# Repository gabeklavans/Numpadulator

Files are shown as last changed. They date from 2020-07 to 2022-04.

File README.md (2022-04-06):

# Numpadulator
 QMK powered numpad + calculator
 
 ## TODO:
 * Write (or borrow) C calculator code
 * Incorporate calculator into Numpadulator
 * ~~Build working prototype~~

RGB Demo
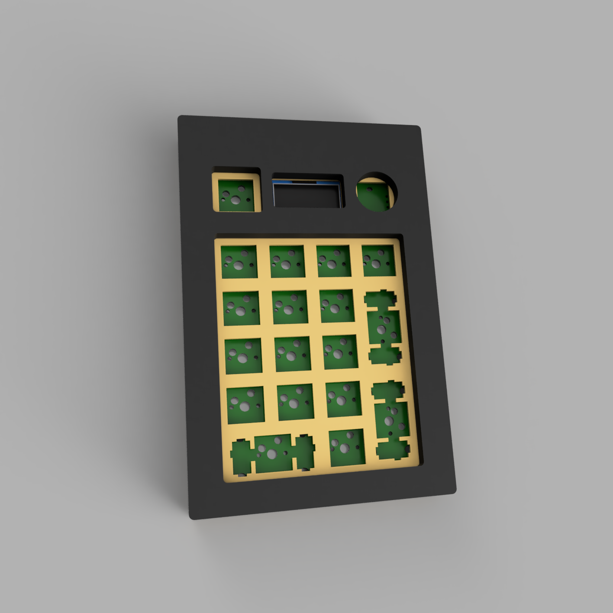
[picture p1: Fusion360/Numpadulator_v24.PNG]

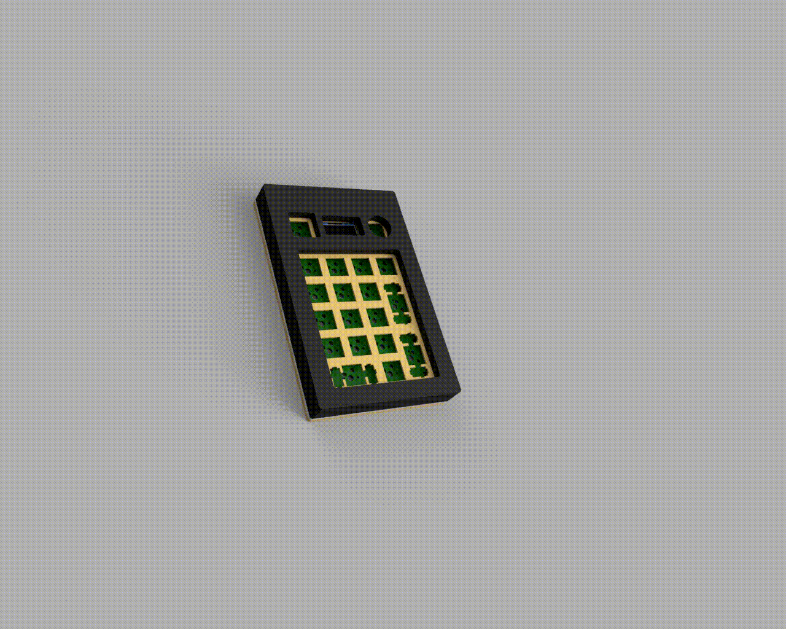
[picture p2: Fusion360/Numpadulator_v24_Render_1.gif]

PCB design

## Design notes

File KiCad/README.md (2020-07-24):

# Numpadulator
 QMK powered numpad + calculator

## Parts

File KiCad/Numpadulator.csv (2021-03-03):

Id | Designator | Package | Quantity | Designation | Supplier and ref
1 | C24,C23,C22,C21,C20,C19,C18,C17,C16,C15,C14,C13,C12,C11,C10,C9,C8,C7,C6,C5,C4,C3,C2,C1 | C_0805_2012Metric | 24 | 0.1uF
2 | D28,D27,D26,D25,D24,D23 | LED_SK6812MINI_PLCC4_3.5x3.5mm_P1.75mm | 6 | SK6812MINI
3 | R1 | R_0805_2012Metric | 1 | 470
4 | MX2,MX3,MX1 | MXOnly-2U-Hotswap | 3 | MX-NoLED
5 | SW16,SW2,SW1,SW12,SW15,SW14,SW13,SW11,SW10,SW9,SW8,SW7,SW5,SW4,SW3 | Cherry-MX_PCB-Mounted_SK6812-MINI-E_Kailh_Socket | 15 | Cherry_MX_RGB_WS2812
6 | SW19 | XDCR_PEC11R-4215F-S0024 | 1 | Rotary_Encoder_Switch
7 | D22,D21,D20 | SK6812-MINI-E | 3 | WS2816
8 | U2 | Adafruit_SSD1306 | 1 | OLED_SSD1306
9 | U1 | PRO_MICRO_C | 1 | PRO_MICRO_C
10 | D19,D18,D17,D16,D15,D14,D13,D12,D11,D10,D9,D8,D7,D6,D5,D4,D3,D2,D1 | D_SOD-123 | 19 | D_Small

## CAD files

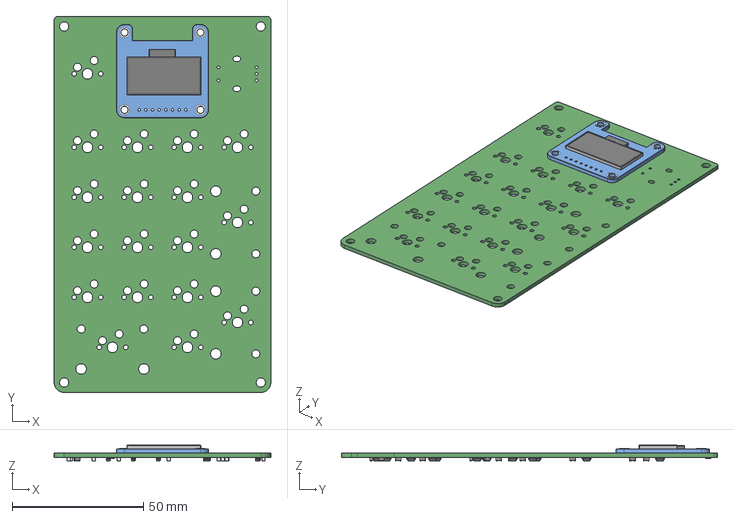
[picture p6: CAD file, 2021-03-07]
KiCad/Numpadulator.step
82.5 x 143.3 x 5.95 mm

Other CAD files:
Fusion360/Numpadulator v25.f3z

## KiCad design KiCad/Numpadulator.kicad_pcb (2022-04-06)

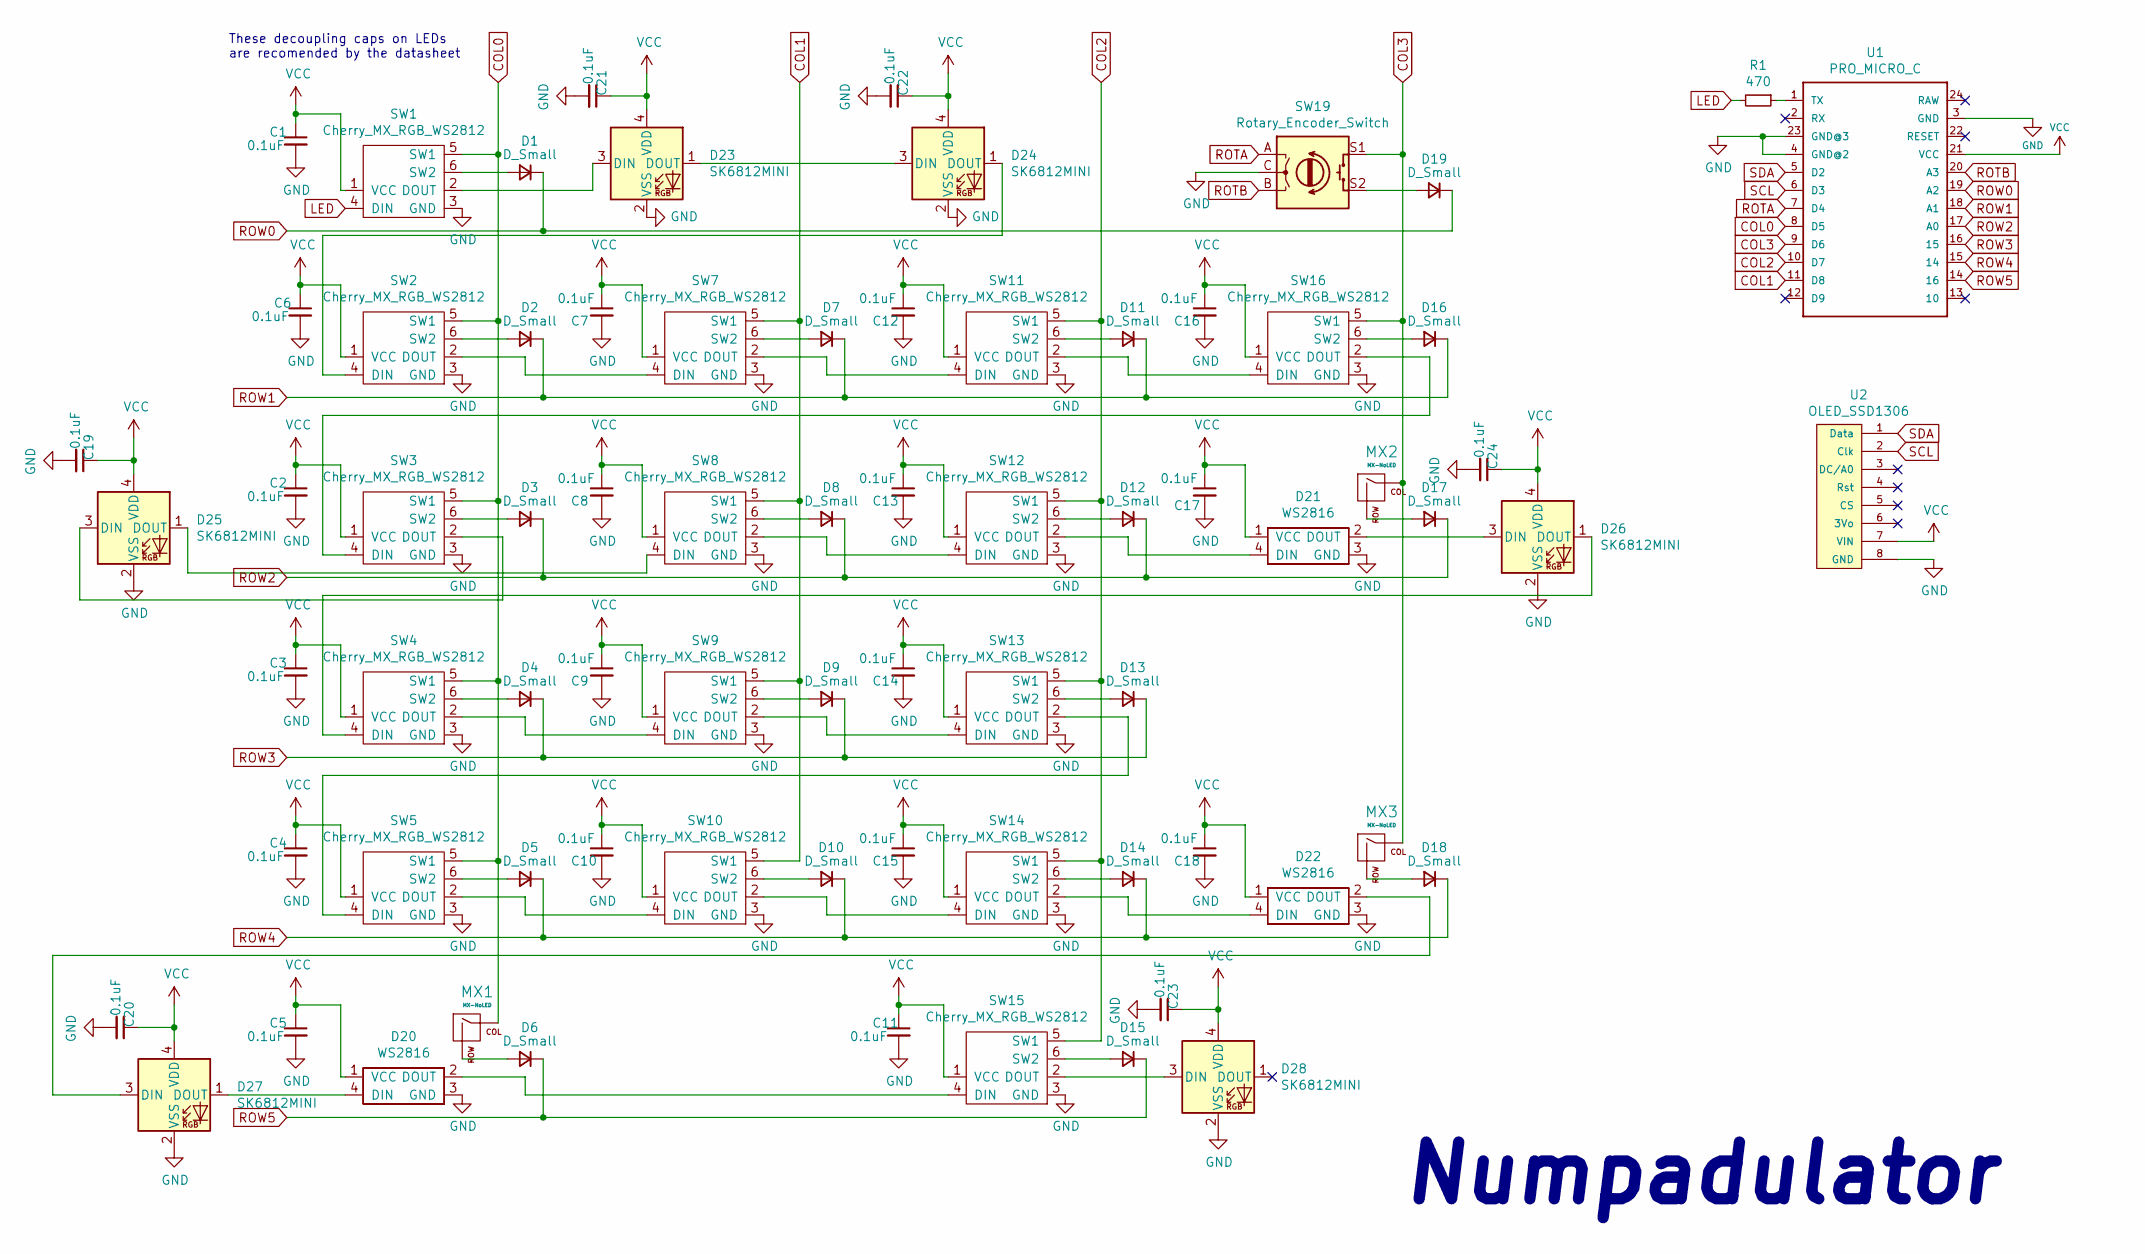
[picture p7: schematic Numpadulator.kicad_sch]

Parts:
C1, C2, C3, C4, C5, C6, C7, C8, C9, C10, C11, C12, C13, C14, C15, C16, C17, C18, C19, C20, C21, C22, C23, C24: 0.1uF; C_0805_2012Metric
D1, D2, D3, D4, D5, D6, D7, D8, D9, D10, D11, D12, D13, D14, D15, D16, D17, D18, D19: D_Small; D_SOD-123
D20, D21, D22: WS2816; SK6812-MINI-E
D23, D24, D25, D26, D27, D28: SK6812MINI; LED_SK6812MINI_PLCC4_3.5x3.5mm_P1.75mm
MX1, MX2, MX3: MX-NoLED; MXOnly-2U-Hotswap
R1: 470; R_0805_2012Metric
SW1, SW2, SW3, SW4, SW5, SW7, SW8, SW9, SW10, SW11, SW12, SW13, SW14, SW15, SW16: Cherry_MX_RGB_WS2812; Cherry-MX_PCB-Mounted_SK6812-MINI-E_Kailh_Socket
SW19: Rotary_Encoder_Switch; XDCR_PEC11R-4215F-S0024
U1: PRO_MICRO_C
U2: OLED_SSD1306; Adafruit_SSD1306

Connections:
COL0: MX1.1 (COL), SW1.5 (SW1), SW2.5 (SW1), SW3.5 (SW1), SW4.5 (SW1), SW5.5 (SW1), U1.8 (D5)
COL1: SW7.5 (SW1), SW8.5 (SW1), SW9.5 (SW1), SW10.5 (SW1), U1.11 (D8)
COL2: SW11.5 (SW1), SW12.5 (SW1), SW13.5 (SW1), SW14.5 (SW1), SW15.5 (SW1), U1.10 (D7)
COL3: MX2.1 (COL), MX3.1 (COL), SW16.5 (SW1), SW19.S1, U1.9 (D6)
GND: C1.2, C2.2, C3.2, C4.2, C5.2, C6.2, C7.2, C8.2, C9.2, C10.2, C11.2, C12.2, C13.2, C14.2, C15.2, C16.2, C17.2, C18.2, C19.2, C20.2, C21.2, C22.2, C23.2, C24.2, D20.3 (GND), D21.3 (GND), D22.3 (GND), D23.2 (VSS), D24.2 (VSS), D25.2 (VSS), D26.2 (VSS), D27.2 (VSS), D28.2 (VSS), SW1.3 (GND), SW2.3 (GND), SW3.3 (GND), SW4.3 (GND), SW5.3 (GND), SW7.3 (GND), SW8.3 (GND), SW9.3 (GND), SW10.3 (GND), SW11.3 (GND), SW12.3 (GND), SW13.3 (GND), SW14.3 (GND), SW15.3 (GND), SW16.3 (GND), SW19.C, U1.3 (GND), U1.4 (GND@2), U1.23 (GND@3), U2.8 (GND)
LED: R1.2, SW1.4 (DIN)
unnamed: D1.2 (A), SW1.6 (SW2)
unnamed: D2.2 (A), SW2.6 (SW2)
unnamed: D3.2 (A), SW3.6 (SW2)
unnamed: D4.2 (A), SW4.6 (SW2)
unnamed: D5.2 (A), SW5.6 (SW2)
unnamed: D6.2 (A), MX1.2 (ROW)
unnamed: D7.2 (A), SW7.6 (SW2)
unnamed: D8.2 (A), SW8.6 (SW2)
unnamed: D9.2 (A), SW9.6 (SW2)
unnamed: D10.2 (A), SW10.6 (SW2)
unnamed: D11.2 (A), SW11.6 (SW2)
unnamed: D12.2 (A), SW12.6 (SW2)
unnamed: D13.2 (A), SW13.6 (SW2)
unnamed: D14.2 (A), SW14.6 (SW2)
unnamed: D15.2 (A), SW15.6 (SW2)
unnamed: D16.2 (A), SW16.6 (SW2)
unnamed: D17.2 (A), MX2.2 (ROW)
unnamed: D18.2 (A), MX3.2 (ROW)
unnamed: D19.2 (A), SW19.S2
unnamed: D20.2 (DOUT), SW15.4 (DIN)
unnamed: D20.4 (DIN), D27.1 (DOUT)
unnamed: D21.2 (DOUT), D26.3 (DIN)
unnamed: D21.4 (DIN), SW12.2 (DOUT)
unnamed: D22.2 (DOUT), D27.3 (DIN)
unnamed: D22.4 (DIN), SW14.2 (DOUT)
unnamed: D23.1 (DOUT), D24.3 (DIN)
unnamed: D23.3 (DIN), SW1.2 (DOUT)
unnamed: D24.1 (DOUT), SW2.4 (DIN)
unnamed: D25.1 (DOUT), SW8.4 (DIN)
unnamed: D25.3 (DIN), SW3.2 (DOUT)
unnamed: D26.1 (DOUT), SW4.4 (DIN)
unnamed: D28.3 (DIN), SW15.2 (DOUT)
unnamed: R1.1, U1.1 (TX)
unnamed: SW2.2 (DOUT), SW7.4 (DIN)
unnamed: SW4.2 (DOUT), SW9.4 (DIN)
unnamed: SW10.2 (DOUT), SW14.4 (DIN)
unnamed: SW5.2 (DOUT), SW10.4 (DIN)
unnamed: SW11.2 (DOUT), SW16.4 (DIN)
unnamed: SW7.2 (DOUT), SW11.4 (DIN)
unnamed: SW8.2 (DOUT), SW12.4 (DIN)
unnamed: SW5.4 (DIN), SW13.2 (DOUT)
unnamed: SW9.2 (DOUT), SW13.4 (DIN)
unnamed: SW3.4 (DIN), SW16.2 (DOUT)
ROTA: SW19.A, U1.7 (D4)
ROTB: SW19.B, U1.20 (A3)
ROW0: D1.1 (K), D19.1 (K), U1.19 (A2)
ROW1: D2.1 (K), D7.1 (K), D11.1 (K), D16.1 (K), U1.18 (A1)
ROW2: D3.1 (K), D8.1 (K), D12.1 (K), D17.1 (K), U1.17 (A0)
ROW3: D4.1 (K), D9.1 (K), D13.1 (K), U1.16 (15)
ROW4: D5.1 (K), D10.1 (K), D14.1 (K), D18.1 (K), U1.15 (14)
ROW5: D6.1 (K), D15.1 (K), U1.14 (16)
SCL: U1.6 (D3), U2.2 (Clk)
SDA: U1.5 (D2), U2.1 (Data)
VCC: C1.1, C2.1, C3.1, C4.1, C5.1, C6.1, C7.1, C8.1, C9.1, C10.1, C11.1, C12.1, C13.1, C14.1, C15.1, C16.1, C17.1, C18.1, C19.1, C20.1, C21.1, C22.1, C23.1, C24.1, D20.1 (VCC), D21.1 (VCC), D22.1 (VCC), D23.4 (VDD), D24.4 (VDD), D25.4 (VDD), D26.4 (VDD), D27.4 (VDD), D28.4 (VDD), SW1.1 (VCC), SW2.1 (VCC), SW3.1 (VCC), SW4.1 (VCC), SW5.1 (VCC), SW7.1 (VCC), SW8.1 (VCC), SW9.1 (VCC), SW10.1 (VCC), SW11.1 (VCC), SW12.1 (VCC), SW13.1 (VCC), SW14.1 (VCC), SW15.1 (VCC), SW16.1 (VCC), U1.21 (VCC), U2.7 (VIN)

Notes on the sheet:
Numpadulator
These decoupling caps on LEDs are recomended by the datasheet

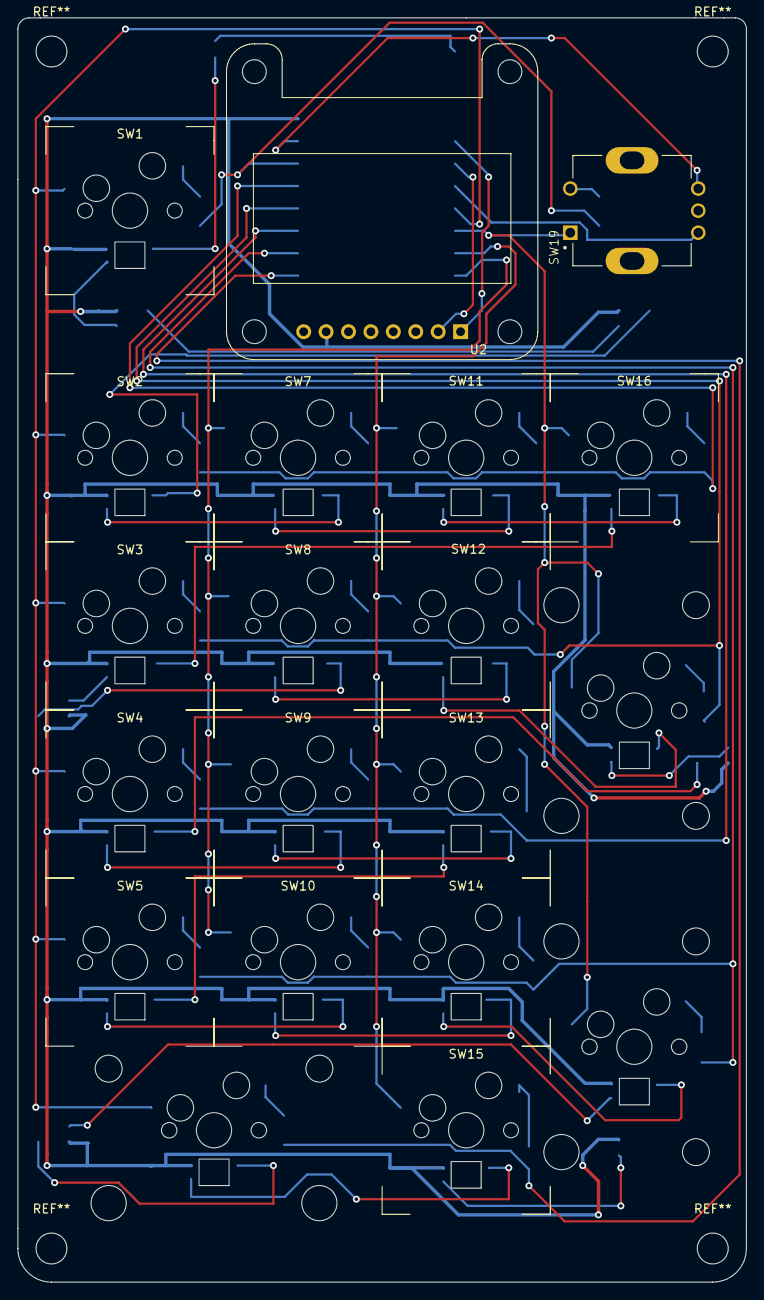
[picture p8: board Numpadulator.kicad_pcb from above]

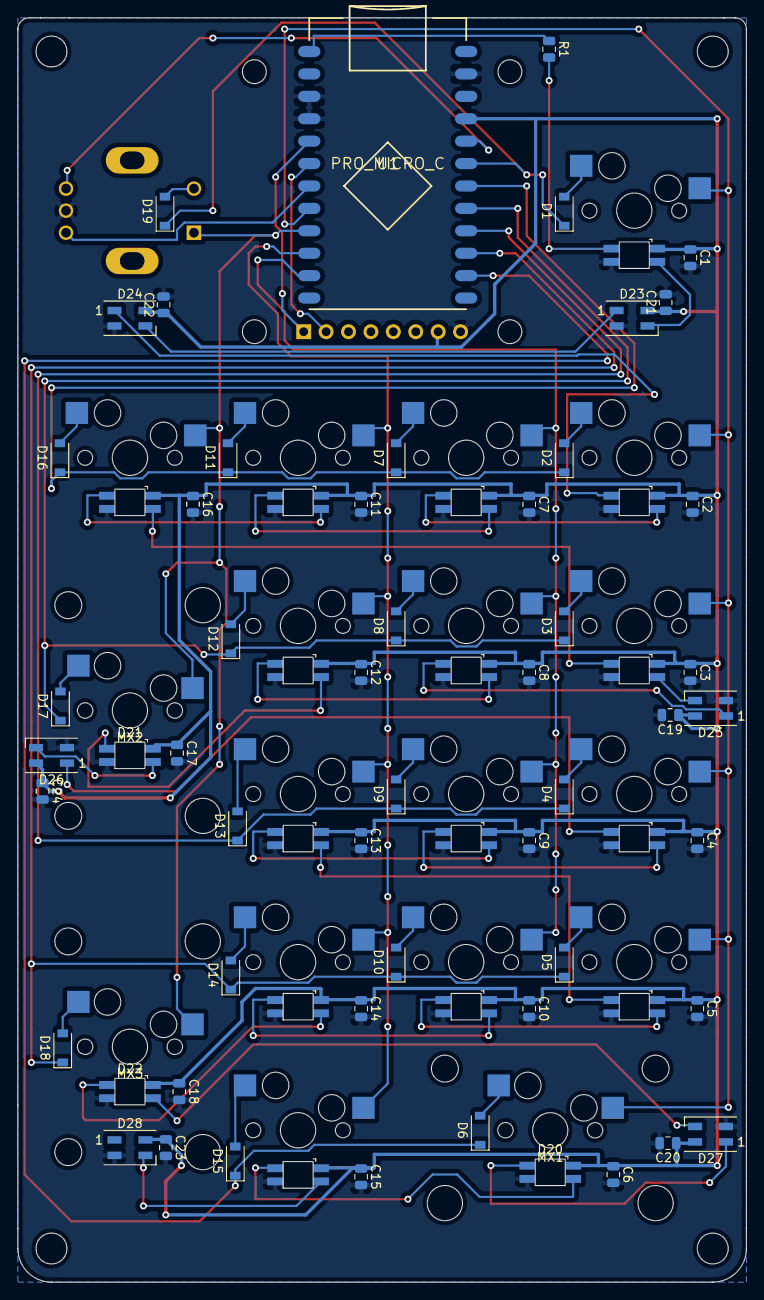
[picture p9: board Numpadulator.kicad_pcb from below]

Board: 2 copper layers, 82.5 x 143.3 mm, 74 parts (51 on the bottom side), 60 nets.

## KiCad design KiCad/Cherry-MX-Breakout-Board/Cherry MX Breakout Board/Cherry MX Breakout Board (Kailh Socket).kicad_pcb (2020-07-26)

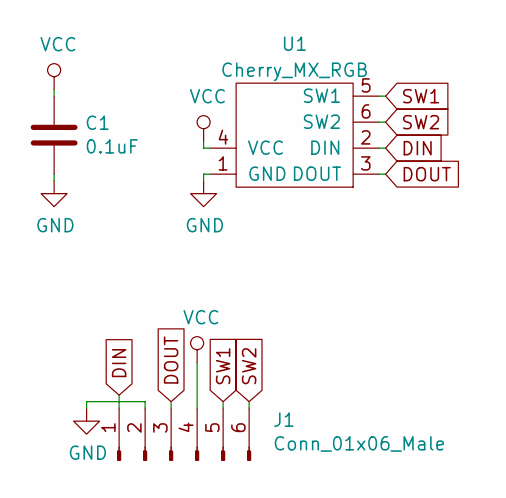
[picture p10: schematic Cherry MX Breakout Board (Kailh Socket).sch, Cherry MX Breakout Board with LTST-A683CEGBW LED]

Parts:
C1: 0.1uF; C_0603_1608Metric
J1: Conn_01x06_Male; PinHeader_1x06_P2.54mm_Vertical
U1: Cherry_MX_RGB; Cherry-MX_Plate-Mounted_LTST-A683CEGBW_Kailh_Socket

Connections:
DIN: J1.1, U1.2 (DIN)
DOUT: J1.3, U1.3 (DOUT)
GND: C1.2, J1.2, U1.1 (GND)
SW1: J1.5, U1.5 (SW1)
SW2: J1.6, U1.6 (SW2)
VCC: C1.1, J1.4, U1.4 (VCC)

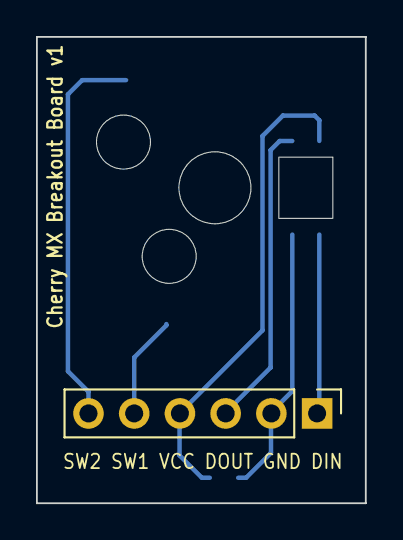
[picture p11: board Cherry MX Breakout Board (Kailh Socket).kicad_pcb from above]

Board: 2 copper layers, 18.3 x 25.9 mm, 3 parts (1 on the bottom side), 6 nets.

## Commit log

2020-07-24 Project creation
    [Numpadulator.kicad_pcb, Numpadulator.sch]
2020-07-24 Added libs/footprints, threw pro into schematic
    [Numpadulator.sch]
2020-07-25 Added MX breakout board submodule
2020-07-26 Moved files to KiCad folder
    [Cherry MX Breakout Board (Kailh Socket)-B_Cu.gbr, Cherry MX Breakout Board (Kailh Socket)-B_Mask.gbr, Cherry MX Breakout Board (Kailh Socket)-B_SilkS.gbr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]
2020-07-26 Dropped in RotEnc and hooked up OLED
    [Numpadulator.sch]
2020-07-29 Added matrix w/o power
    [Numpadulator.sch]
2020-07-29 Started to make look better
    [Numpadulator.sch]
2020-07-29 Added targetting silk to mx footprint
    also threw in footprint for my rotary encoder
2020-07-29 Reworked main matrix schem
    [Numpadulator.sch]
2020-07-29 A little cleanup
    [Numpadulator.sch]
2020-07-29 Started fleshing out pcb, need to change large keys
    [Numpadulator.sch]
2020-07-30 Updated new combined mx led footprint
2020-07-30 More layout and frustration 3:
    [Numpadulator.kicad_pcb, Numpadulator.sch]
2020-07-30 Laid out PCB
    [Numpadulator.kicad_pcb]
2020-07-30 Better PCB layout
    [Numpadulator.kicad_pcb]
2020-08-09 Moved MCU via the Genius of WIll
    [Numpadulator.kicad_pcb, Numpadulator.sch]
2020-10-28 Pic and fusion360 proj file
    [Numpadulator v15.f3d]
2021-01-02 Traced edge cuts
    [Numpadulator.kicad_pcb]
2021-01-05 add some power to the caps
    [Numpadulator.kicad_pcb]
2021-01-06 started some LED routing
    [Numpadulator.kicad_pcb]
2021-01-07 added some whack wiring for LEDs and some Columns
    [Numpadulator.kicad_pcb, Numpadulator.sch]
2021-01-30 Added tracks up to the rows and random shit
    [Numpadulator.kicad_pcb, Numpadulator.step]
2021-01-31 Actually aligned some stuff
    [Numpadulator.kicad_pcb]
2021-01-31 literally nudged the top two up so slightly wow
    [Numpadulator.kicad_pcb, Numpadulator.step]
2021-01-31 nudge track
    [Numpadulator.kicad_pcb, Numpadulator.step]
2021-01-31 Actually made the thing symmetric
    [Numpadulator.kicad_pcb]
2021-01-31 fixed track
    [Numpadulator.kicad_pcb]
2021-01-31 flipped top right 1.5u. now the bottom right...
    [Numpadulator.kicad_pcb, Numpadulator.step]
2021-01-31 flipped the side 1.5us. ugh.
    [Numpadulator.kicad_pcb]
2021-01-31 update step file
    [Numpadulator.step]
2021-02-02 Wired up rows, realized there is something wrong with the 2u keys rows in the schematic...
    [Numpadulator.kicad_pcb, Numpadulator.sch]
2021-02-05 generate gerbs and pos plots
    [Numpadulator-B_Cu.gbr, Numpadulator-B_Mask.gbr, Numpadulator-B_Paste.gbr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]
2021-02-12 Switched + and return to be in right order and orientation...also maybe finished routing??
    [Numpadulator.kicad_pcb]
2021-02-12 FINISHED THE WIRING except now I need to add the underglow LEDs...
    [Numpadulator.kicad_pcb]
2021-02-12 add resistor coming from LED pin
    [Numpadulator.kicad_pcb, Numpadulator.sch]
2021-02-14 Update fusion archive file
    [Numpadulator v15.f3d, Numpadulator v25.f3z]
2021-02-14 got underglow LEDs in schematic... gotta wire them up now
    [Numpadulator.sch]
2021-02-14 forgot to save
    [Numpadulator.kicad_pcb, Numpadulator.sch]
2021-03-03 PLACED EVERYTHING I THINK
    [Numpadulator.kicad_pcb, Numpadulator.sch]
2021-03-03 made some GND SPACE
    [Numpadulator.kicad_pcb]
2021-03-03 now.. they should be placed right... maybe...
    [Numpadulator.kicad_pcb]
2021-03-03 jk for real this time lololol
    [Numpadulator.kicad_pcb]
2021-03-03 10,000th times the charm!
    [Numpadulator.kicad_pcb]
2021-03-03 I crave... something
    [Numpadulator.kicad_pcb]
2021-03-03 it.. might be done now???!?
    [Numpadulator.kicad_pcb]
2021-03-03 made gerbs and fixed buggs
    [Numpadulator-B_Cu.gbr, Numpadulator-B_Mask.gbr, Numpadulator-B_Paste.gbr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]
2021-03-03 updated gerbers
    [Numpadulator-B_Cu.gbr, Numpadulator-B_Mask.gbr, Numpadulator-B_Paste.gbr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]
2021-03-07 made it... holier
    [Numpadulator.kicad_pcb, Numpadulator.step]
2022-04-06 Convert schematic and pcb to KiCad 6
    [Numpadulator.kicad_pcb, Numpadulator.kicad_sch]

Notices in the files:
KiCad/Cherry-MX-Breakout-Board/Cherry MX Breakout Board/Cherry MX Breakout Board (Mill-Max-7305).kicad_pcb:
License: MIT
